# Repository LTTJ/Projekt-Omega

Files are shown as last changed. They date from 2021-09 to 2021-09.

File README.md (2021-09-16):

# Projekt-Omega

## Inhaltsverzeichnis
* [Kurzbeschreibung](#kurzbeschreibung)
* [Hardware](#hardware)
* [Software](#software)
  * [Indoor](#indoor)
  * [Outdoor](#outdoor)
  * [APP](#app)
  * [Node-RED](#node-red)
 
## Kurzbeschreibung
Dies ist "Projekt-Omega" - ein Smart-Home Projekt, welches für das Modul Soft Skills und Technische Kompetenzen als Prüfungsleistung entstanden ist. Die Aufgabe war es, ein Gerät zu entwickeln, das den Alltag angenehmer gestaltet oder ein konkretes Problem löst. Als weitere Bedingung musste mindestens ein Teil des Gadgets aus dem 3D-Drucker oder dem Lasercutter kommen. 

Das Ergebnis besteht aus zwei Prototypen: das Indoor-Haus und das Outdoor-Haus.
Prototyp-Drinnen
Prototyp-Draußen

## Hardware
Indoor-Haus:
* WEMOS D1 mini
* OLED Display
* DC Power Shield
* Rotary Encoder
* DHT Shield
* MQ-3 Sensor
* Kipp-Schalter
* Buzzer Shield
* Tripler Base

Outdoor-Haus:
* WEMOS D1 mini
* Battery Shield

Im Folgenden sind die Schaltpläne der beiden Häuser dargestellt.
Schaltplan-Indoor
Schaltplan-Outdoor

## Software
# Indoor
Software-Indoor

Die Software für das Indoor Haus ist einfach zusammenfassen, bietet jedoch eine gewisse Komplexität. Wurde die "requestData"-Flag gesetzt, so wird über MQTT die Node-RED Instanz angestoßen. Diese fordert dann bei der entsprechenden API die benötigten Daten an. Diese Daten werden an das Haus zurückgeschickt und können in der "handle MQTT" Phase verarbeitet werden. 

Nach der Verarbeitung sämtlicher MQTT Nachrichten wird geprüft, ob noch weitere Anfragen verarbeitet werden müssen oder ob der Bildschirm deaktiviert ist. Ist dies der Fall, werden die Displays geleert und die Schleife springt zum Anfang zurück. Die Variable "lightOn" kann mittels MQTT, also der App, und per Interrupt an dem Schalter vorne am Haus verändert werden.

Sind die Displays hingegen aktiviert und sollen Daten anzeigen, wird auf einem Display ein Auswahlmenü eingeblendet und auf dem anderen Display werden die Daten angezeigt. Mithilfe des Drehimpulsgebers (Schornstein) ist das Menü navigierbar. Auch diese Interaktion wird über Interrupt und die App realisiert, sodass nicht immer in der Loop erfragt werden muss, ob eine Auswahl stattgefunden hat.

# Outdoor

Software-Outdoor

Das Outdoor-Haus erlaubt keine Interaktion und ist so implementiert, dass es von überall Daten aufnehmen und an das Indoor-Haus senden kann. Dazu verbindet sich der Mikrocontroller zuerst mit dem WiFi und baut eine Verbindung zum MQTT-Broker auf. Daraufhin folgt eine Aufnahmereihe von 10 Aufnahmen, aus welchen ein Mittelwert errechnet wird. Ist dies geschehen, werden die Daten mittels MQTT an alle abonnierenden MQTT-Teilnehmer gesendet (Indoor-Haus). Abschließend geht der Controller für eine Minute in den Deep Sleep Modus. Um aus diesem Modus wieder "erwachen" zu können, müssen der D0 und der RST Pin miteinander verbunden sein. Die Nutzung des Deep Sleep Modus hat zwei verschiedene Gründe:

* Der Wemos d1 Mini produziert im Dauerbetrieb eine enorme Menge an Wärme, welche unweigerlich die Aufnahme der Temperaturwerte verfälscht. In einigen Tests wurden Temperaturabweichungen bis zu 10 °C festgestellt.
* Da der Wemos eine Minute lang nahezu ausgeschaltet ist, wird dabei keine Energie verbraucht und der Akku muss seltener geladen werden.

## Bibliotheken
Um das Projekt realisieren zu können, wurden diverse Bibliotheken verwendet. Diese Bibliotheken können alle im Library Manger der Arduino IDE heruntergeladen werden:

- "Adafruit GFX Library" by Adafruit, v1.10.10
- "Adafruit SSD1306 Wemos Mini OLED" by Adafruit + mcauser, v1.1.2
- "ArduinoMqttClient" by Arduino, v0.1.5
- "WiFiManager" by tzapu,tablatronix, v2.0.3-alpha
- "DHT sensor library" by Adafruit, v1.3.9
- "Time" by Michael Margolis, v1.6.1 (https://github.com/PaulStoffregen/Time)

<p>Da die Bibliothek "Adafruit SSD1306 Wemos Mini OLED" die selben Klassennamen hat wie die Bibliothek "Adafruit SSD1306" by Adafruit, besteht die Gefahr, dass der Compiler nicht die richtige Klasse zuordnen kann. Um dieses Problem zu umgehen, wurden die Klassen in der Bibliothek "Adafruit SSD1306 Wemos Mini OLED" mittels find and replace so bearbeitet, dass alle Klassennamen um den Suffix "_WEMOS" ergänzt wurden. Auf diese Weise können beide Bibliotheken simultan verwendet werden.

# APP

Die Implementierung der App erfolgte online mit Hilfe der Website MIT App Inventor. Durch die Erweiterung eines Beispielprogramms, welches bereits MQTT implementiert hatte, konnte relativ simpel eine einfache App gestaltet und mit MQTT-Funktionalität ausgestattet werden.

Blynk kam in diesem Projekt nicht mehr zum Einsatz. Grund dafür ist Blynks neuer Businessplan, der nicht mit Zielen des Projekts verainbar ist.

# Node-RED

Node-RED-flow

Der Node-RED-Flow ist aktuell darauf begrenzt, Anfragen an die SpaceX-API zu triggern und die Daten dann wieder mittels MQTT zu übermitteln.

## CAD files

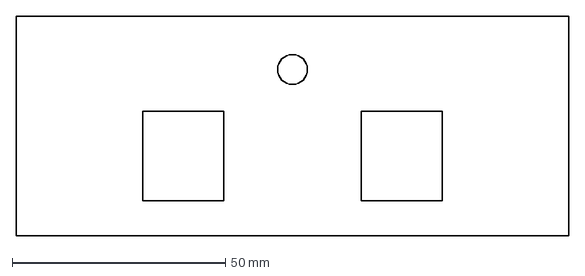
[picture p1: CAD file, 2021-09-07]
Hardware/Home/DXF/wood_front.dxf
129.5 x 51.5 mm

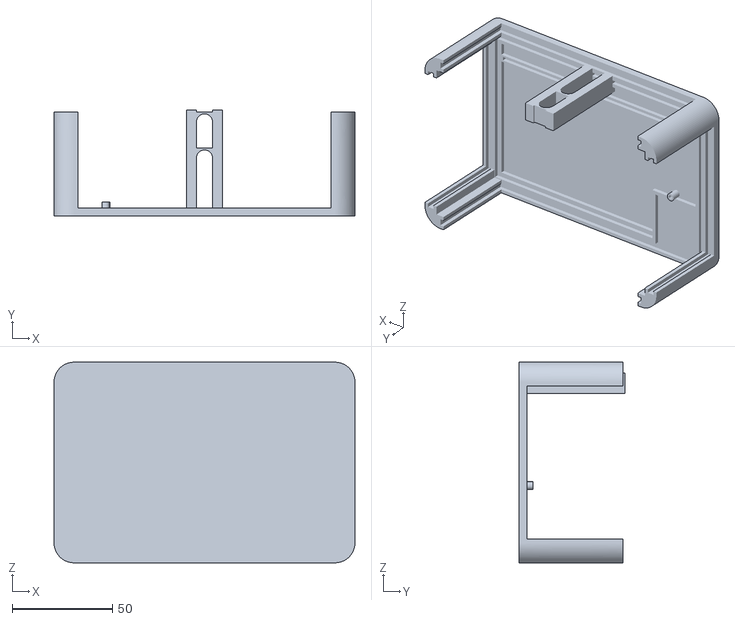
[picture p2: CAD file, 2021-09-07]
Hardware/Home/STL/bottom.stl
150.0 x 53.0 x 100.0

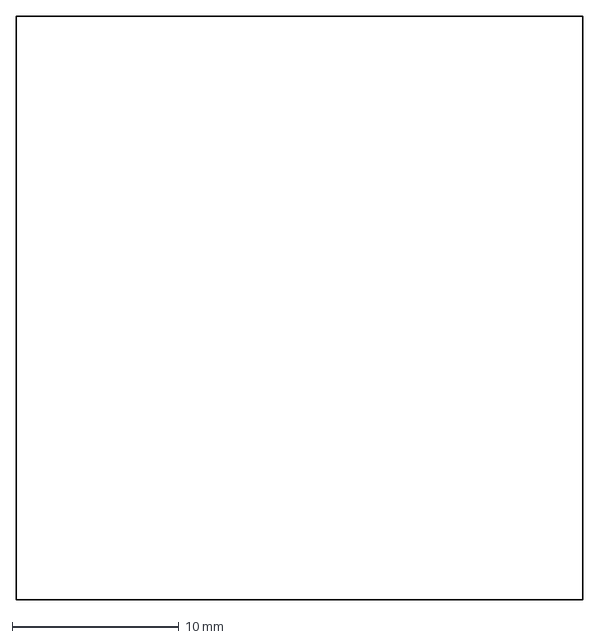
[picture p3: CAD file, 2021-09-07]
Hardware/SmallHome/DXF/wood_small_small.dxf
34.0 x 35.0 mm

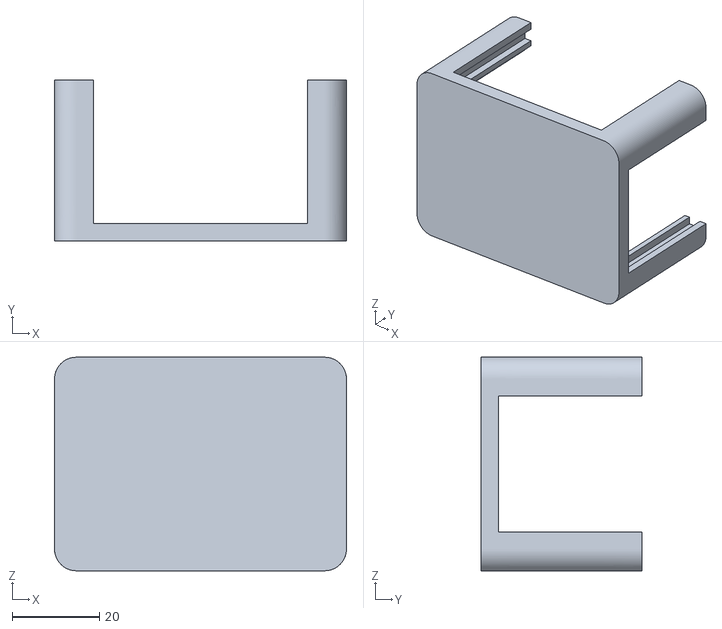
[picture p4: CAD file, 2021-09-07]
Hardware/SmallHome/STL/small_bottom.stl
67.0 x 37.0 x 49.0

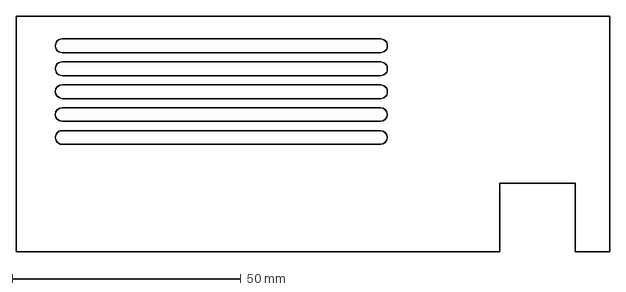
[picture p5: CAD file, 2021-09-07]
Hardware/Home/DXF/wood_back.dxf
129.5 x 51.5 mm

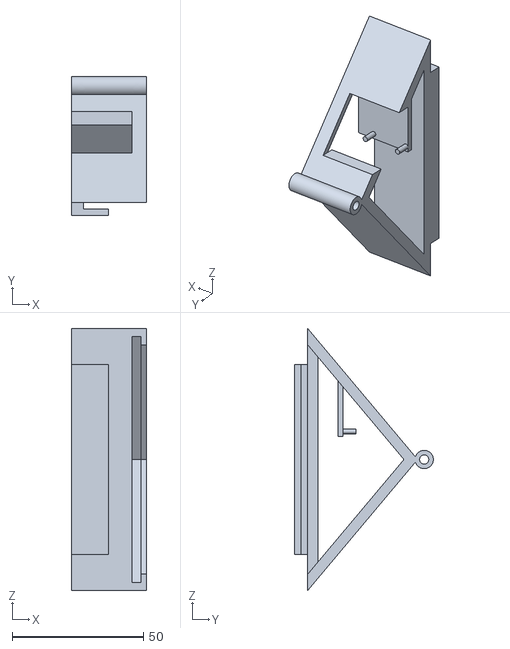
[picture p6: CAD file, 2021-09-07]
Hardware/Home/STL/roof_foot_left.stl
28.5 x 53.0 x 100.0

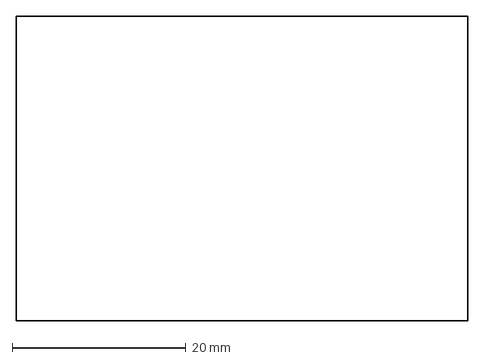
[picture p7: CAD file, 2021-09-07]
Hardware/SmallHome/DXF/wood_small_big.dxf
52.0 x 35.0 mm

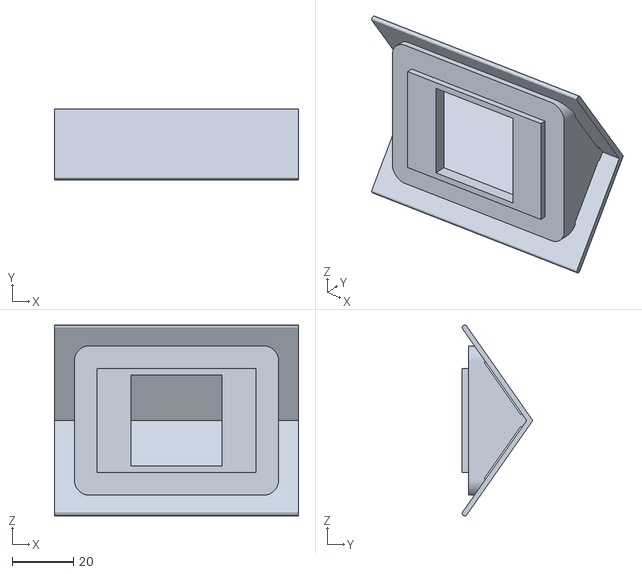
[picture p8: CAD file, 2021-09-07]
Hardware/SmallHome/STL/small_top.stl
80.0 x 23.2 x 62.6

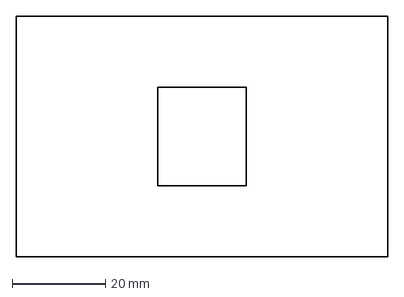
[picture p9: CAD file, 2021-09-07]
Hardware/Home/DXF/wood_right.dxf
79.5 x 51.5 mm

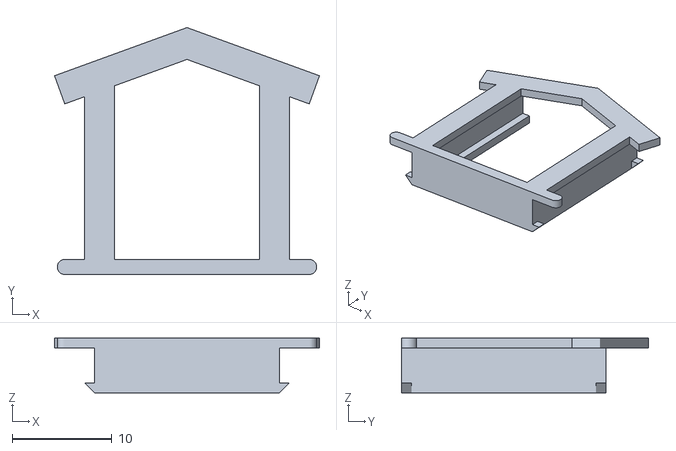
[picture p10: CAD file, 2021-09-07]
Hardware/Home/STL/window_side.stl
26.6 x 24.7 x 5.50

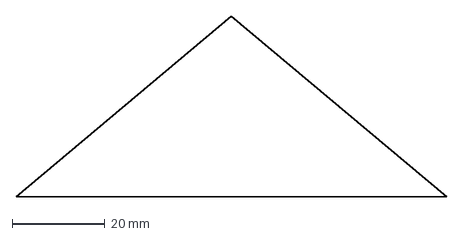
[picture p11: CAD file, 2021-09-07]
Hardware/Home/DXF/wood_roof_right.dxf
93.0 x 39.0 mm

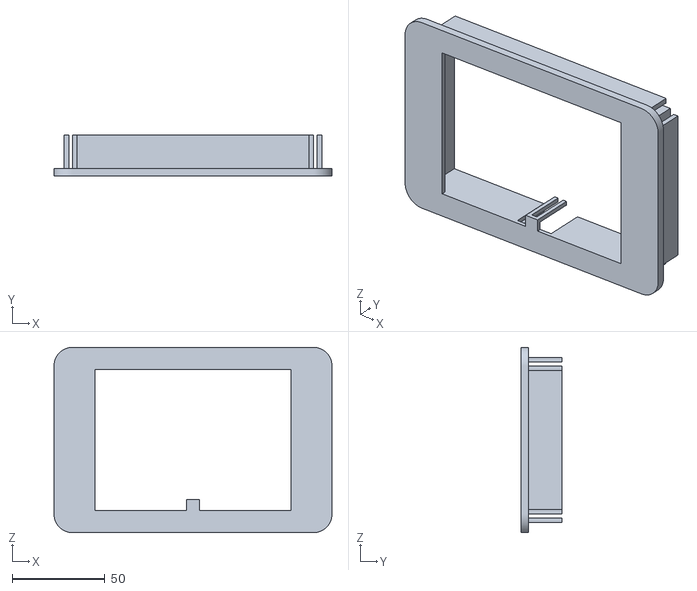
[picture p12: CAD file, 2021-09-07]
Hardware/Home/STL/top.stl
150.0 x 22.0 x 100.0

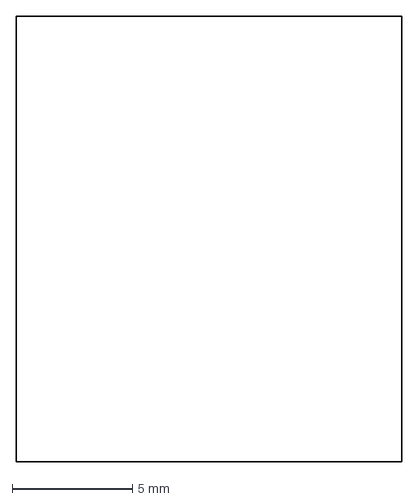
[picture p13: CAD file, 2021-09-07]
Hardware/Home/DXF/window_pane.dxf
16.0 x 18.5 mm

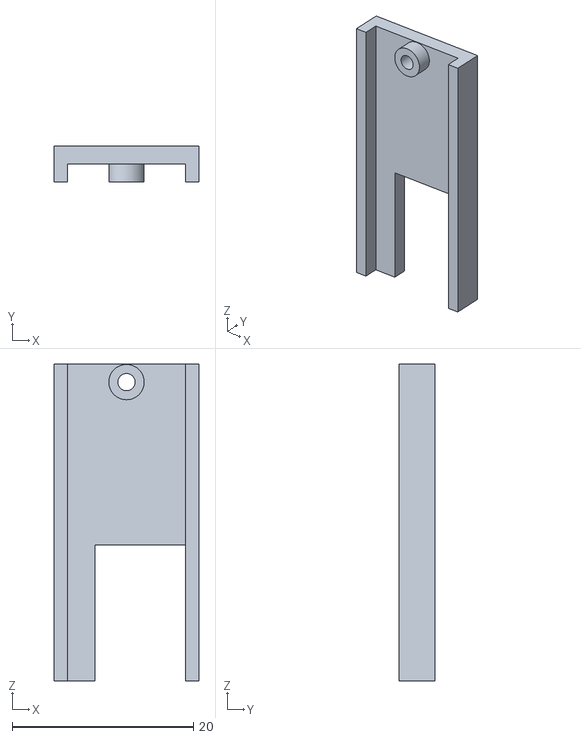
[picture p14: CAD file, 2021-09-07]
Hardware/Home/STL/power_halterung.stl
16.0 x 4.00 x 35.0

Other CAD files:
Hardware/Home/DXF/wood_roof_front.dxf
Hardware/Home/STL/roof_foot_right.stl
Hardware/Home/DXF/wood_left.dxf
Hardware/Home/STL/roof.stl
Hardware/Home/DXF/wood_roof_back.dxf
Hardware/Home/DXF/wood_roof_left.dxf
Hardware/Home/Inventor/bottom.ipt
Hardware/Home/Inventor/chimney.ipt
Hardware/Home/Inventor/power_halterung.ipt
Hardware/Home/Inventor/roof.ipt
Hardware/Home/Inventor/roof_foot_left.ipt
Hardware/Home/Inventor/roof_foot_right.ipt
Hardware/Home/Inventor/top.ipt
Hardware/Home/Inventor/window_pane.ipt
Hardware/Home/Inventor/window_side.ipt
Hardware/Home/Inventor/wood_back.ipt
Hardware/Home/Inventor/wood_front.ipt
Hardware/Home/Inventor/wood_left.ipt
Hardware/Home/Inventor/wood_right.ipt
Hardware/Home/Inventor/wood_roof_back.ipt
Hardware/Home/Inventor/wood_roof_front.ipt
Hardware/Home/Inventor/wood_roof_left.ipt
Hardware/Home/Inventor/wood_roof_right.ipt
Hardware/Home/STL/chimney.stl
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

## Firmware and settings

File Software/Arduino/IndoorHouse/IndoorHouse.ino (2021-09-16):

/*
By LTTJ
~ September 2021
*/

// Einbinden der benötigten Bibliotheken
#include "secrets.h"
#include "Definitions.h"
// OLED
#include <SPI.h>
#include <Wire.h>
#include <Adafruit_GFX.h>
#include <Adafruit_SSD1306_WEMOS.h>

// MQTT
#include <ArduinoMqttClient.h>

// WIFI
#include <ESP8266WiFi.h>  //https://github.com/esp8266/Arduino
#include <WiFiManager.h>

// CLOCK
#include "Clock.h"
#include <WiFiUdp.h>
#include <TimeLib.h>

// DHT
#include <Adafruit_Sensor.h>
#include <DHT.h>
#include <DHT_U.h>

#include "Menu.h"
#include "Scroll.h"

// https://forum.arduino.cc/t/single-line-define-to-disable-code/636044/2
// Aktiviere und deaktiviere Spezielle Serialausgaben über eine einfache Flag.
// Dies macht es wesentlich einfacher mit dem Serial Monitor große Programme zu debuggen.
#define DEBUG true
#define DEBUG_SERIAL \
  if (DEBUG) Serial

#define DEBUG_DHT false
#define DEBUG_DHT_SERIAL \
  if (DEBUG_DHT) Serial

#define DEBUG_MQTT true
#define DEBUG_MQTT_SERIAL \
  if (DEBUG_MQTT) Serial


Adafruit_SSD1306_WEMOS display1(OLED_RESET);
Adafruit_SSD1306_WEMOS display2(OLED_RESET);

Menu menu;
Scroll scroll;


DHT_Unified dht(DHTPIN, DHTTYPE);

uint32_t delayMS;
uint32_t lastDHTCheck;


WiFiClient client;
WiFiUDP Udp;
MqttClient mqttClient(client);

Clock c;

volatile bool lightsOn = true;
volatile bool switchFlag = false;

volatile bool modeChanged = false;
volatile bool requestData = false;

// ISR für den Interrupt des Schalters an D5
ICACHE_RAM_ATTR void SWITCHHandler(void) {
  switchFlag = true;
  modeChanged = true;
  menu.setChanged(true);
  lightsOn = !lightsOn;
}


// Diese Variablen werden gebraucht, um festzustellen, ob und wie sich der Encoder gedreht hat
// volatile int count = 0;
volatile int lastCLK = 0;
volatile bool countChanged = false;


// Buffer für Daten, die sonst über MQTT wieder erfragt werden müssten
time_t prevDisplay = 0;  // when the digital clock was displayed

float outdoorTempPrev = 0;
float outdoorTemp = 0;
float outdoorHumidPrev = 0;
float outdoorHumid = 0;

float indoorTemp = 0;
float indoorTempPrev = 0;
float indoorHumid = 0;
float indoorHumidPrev = 0;

String SpaceXName;
String SpaceXLaunchDate;

// interrupt handlers
// drehen des Encoders
ICACHE_RAM_ATTR void ClockChanged(void) {
  int clkValue = digitalRead(CLK);  //Read the CLK pin level
  int dtValue = digitalRead(DT);    //Read the DT pin level
  if (lastCLK != clkValue) {
    lastCLK = clkValue;
    //  count += (clkValue != dtValue ? 1 : -1);  //CLK and inconsistent DT + 1, otherwise - 1
    if (clkValue != dtValue) {
      menu.increment();
    } else {
      menu.decrement();
    }
  }
  countChanged = true;
}

// klicken des Encoders
ICACHE_RAM_ATTR void SWChanged(void) {
  uint8_t oldMode = menu.getSelectedMode();
  menu.select();
  modeChanged = (oldMode != menu.getSelectedMode());
  requestData = true;
}


void setup() {
#if DEBUG_DHT == true || DEBUG == true || DEBUG_MQTT == true
  Serial.begin(115200);
#endif

  pinMode(SWITCHPIN, INPUT_PULLUP);
  attachInterrupt(digitalPinToInterrupt(SWITCHPIN), SWITCHHandler, CHANGE);

  pinMode(SW, INPUT_PULLUP);
  //digitalWrite(SW, HIGH);
  pinMode(CLK, INPUT_PULLUP);
  pinMode(DT, INPUT);
  attachInterrupt(digitalPinToInterrupt(CLK), ClockChanged, CHANGE);
  attachInterrupt(digitalPinToInterrupt(SW), SWChanged, FALLING);


  display1.begin(SSD1306_SWITCHCAPVCC, address1);
  display2.begin(SSD1306_SWITCHCAPVCC, address2);


  display1.setTextColor(WHITE);
  display1.clearDisplay();
  display1.setTextWrap(false);

  display2.setTextColor(WHITE);
  display2.clearDisplay();
  display2.setTextWrap(false);
  display2.setCursor(0, 0);
  display2.print("DHT init");
  display2.display();

  // Temp and Humidity Sensor init
  dht.begin();
  DEBUG_DHT_SERIAL.println(F("DHTxx Unified Sensor Example"));
  // Print temperature sensor details.
  sensor_t sensor;
  dht.temperature().getSensor(&sensor);
  DEBUG_DHT_SERIAL.println(F("------------------------------------"));
  DEBUG_DHT_SERIAL.println(F("Temperature Sensor"));
  DEBUG_DHT_SERIAL.print(F("Sensor Type: "));
  DEBUG_DHT_SERIAL.println(sensor.name);
  DEBUG_DHT_SERIAL.print(F("Driver Ver:  "));
  DEBUG_DHT_SERIAL.println(sensor.version);
  DEBUG_DHT_SERIAL.print(F("Unique ID:   "));
  DEBUG_DHT_SERIAL.println(sensor.sensor_id);
  DEBUG_DHT_SERIAL.print(F("Max Value:   "));
  DEBUG_DHT_SERIAL.print(sensor.max_value);
  DEBUG_DHT_SERIAL.println(F("°C"));
  DEBUG_DHT_SERIAL.print(F("Min Value:   "));
  DEBUG_DHT_SERIAL.print(sensor.min_value);
  DEBUG_DHT_SERIAL.println(F("°C"));
  DEBUG_DHT_SERIAL.print(F("Resolution:  "));
  DEBUG_DHT_SERIAL.print(sensor.resolution);
  DEBUG_DHT_SERIAL.println(F("°C"));
  DEBUG_DHT_SERIAL.println(F("------------------------------------"));
  // Print humidity sensor details.
  dht.humidity().getSensor(&sensor);
  DEBUG_DHT_SERIAL.println(F("Humidity Sensor"));
  DEBUG_DHT_SERIAL.print(F("Sensor Type: "));
  DEBUG_DHT_SERIAL.println(sensor.name);
  DEBUG_DHT_SERIAL.print(F("Driver Ver:  "));
  DEBUG_DHT_SERIAL.println(sensor.version);
  DEBUG_DHT_SERIAL.print(F("Unique ID:   "));
  DEBUG_DHT_SERIAL.println(sensor.sensor_id);
  DEBUG_DHT_SERIAL.print(F("Max Value:   "));
  DEBUG_DHT_SERIAL.print(sensor.max_value);
  DEBUG_DHT_SERIAL.println(F("%"));
  DEBUG_DHT_SERIAL.print(F("Min Value:   "));
  DEBUG_DHT_SERIAL.print(sensor.min_value);
  DEBUG_DHT_SERIAL.println(F("%"));
  DEBUG_DHT_SERIAL.print(F("Resolution:  "));
  DEBUG_DHT_SERIAL.print(sensor.resolution);
  DEBUG_DHT_SERIAL.println(F("%"));
  DEBUG_DHT_SERIAL.println(F("------------------------------------"));
  // Set delay between sensor readings based on sensor details.
  delayMS = sensor.min_delay / 1000;

  //display2.clearDisplay();
  display2.setCursor(0, 12);
  display2.print("DHT done");
  display2.display();

  // starting WiFi setup
  WiFiManager wifiManager;
  wifiManager.setWiFiAutoReconnect(true);
  DEBUG_SERIAL.println("starting connection");
  display1.clearDisplay();
  display1.println("connecting...");
  display1.display();
  wifiManager.autoConnect("IndoorHouse");
  DEBUG_SERIAL.println("connected...yeey :)");
  display1.clearDisplay();
  display1.println("connected!");
  display1.display();

  // MQTT setup
  mqttClient.setId("IndoorHouse");
  mqttClient.setUsernamePassword(username, password);

  // String willPayload = "oh no!";
  // bool willRetain = true;
  // int willQos = 1;

  // mqttClient.beginWill(willTopic, willPayload.length(), willRetain, willQos);
  // mqttClient.print(willPayload);
  // mqttClient.endWill();


  if (!mqttClient.connect(broker, port)) {
    DEBUG_MQTT_SERIAL.print("MQTT connection failed! Error code = ");
    DEBUG_MQTT_SERIAL.println(mqttClient.connectError());
    while (1)
      ;
  }
  mqttClient.subscribe(OUTDOOR_TEMP_TOPIC);
  mqttClient.subscribe(OUTDOOR_HUMID_TOPIC);
  mqttClient.subscribe(DISPLAY_SELECTION_TOPIC);
  mqttClient.subscribe(DISPLAY_ACTIVE_TOPIC);

  mqttClient.subscribe(API_SPACEX_NAME);
  mqttClient.subscribe(API_SPACEX_LAUNCHDATE);

  // ermittele Zeit mittels UDP
  Udp.begin(localPort);
  setSyncProvider(getNtpTime);
  setSyncInterval(300);
}

void loop() {
  // Falls Daten von Node-RED erfragt werden müssen, wird die requestData Flag gesetzt, sodass an dieser Stelle dann die Daten erbittet werden können.
  // Dies geschieht, indem eine entsprechende Nachricht an Node-RED geschickt wird, welche das Versenden der Daten triggert.
  if (requestData) {
    switch (menu.getSelectedMode()) {
      case SPACEX:
        mqttClient.beginMessage(API_SPACEX);
        mqttClient.print(1);
        mqttClient.endMessage();
        DEBUG_SERIAL.println("sending SpaceX request");
        break;
      default:
        break;
    }
    requestData = false;
  }

  // Falls MQTT Nachrichten kommen, verarbeite sie entsprechend
  handleMQTT();


  // Wenn wir kein Licht an haben, dann werden hier die Displays deaktiviert und das Programm braucht nicht weiter machen, da nichts mehr angezeigt werden soll -> return
  if (!lightsOn) {
    DEBUG_SERIAL.println("lights off");
    if (switchFlag) {
      display1.clearDisplay();
      display1.display();
      display2.clearDisplay();
      display2.display();
      DEBUG_SERIAL.println("displays off");
      switchFlag = false;
    }
    return;
  }


  // entsprechend des ausgewählten Mode im Menu werden bestimmte Anzeigen gerendert.
  switch (menu.getSelectedMode()) {
    case INDOOR_DATA_MODE:
      // get new data from the sensor periodically
      getDHTData();

      // display the indoor values
      if (indoorTempPrev != indoorTemp || indoorHumidPrev != indoorHumid || modeChanged) {
        display2.clearDisplay();
        display2.setCursor(0, 5);
        display2.print("Indoor");
        display2.setCursor(0, 15);
        display2.print(F("Tmp: "));
        display2.print(indoorTemp);
        // display2.println(F("°C"));

        display2.setCursor(0, 25);
        display2.print(F("Hum: "));
        display2.print(indoorHumid);
        display2.display();
        // display2.println(F("%"));
        indoorHumidPrev = indoorHumid;
        indoorTempPrev = indoorTemp;

        modeChanged = false;
      }
      break;
    case OUTDOOR_DATA_MODE:
      if (outdoorTempPrev != outdoorTemp || outdoorHumidPrev != outdoorHumid || modeChanged) {
        display2.clearDisplay();
        display2.setCursor(0, 5);
        display2.print("Outdoor");
        display2.setCursor(0, 15);
        display2.print(F("Tmp: "));
        display2.print(outdoorTemp);
        // display2.println(F("°C"));

        display2.setCursor(0, 25);

        display2.print(F("Hum: "));
        display2.print(outdoorHumid);
        //  display2.println(F("%"));

        display2.display();
        outdoorTempPrev = outdoorTemp;
        outdoorHumidPrev = outdoorHumid;
        modeChanged = false;
      }
      break;
    case DIGITAL_CLOCK:
      if (timeStatus() != timeNotSet) {
        if (now() != prevDisplay || modeChanged) {  //update the display only if time has changed
          prevDisplay = now();
          display2.clearDisplay();
          c.displayDigital(&display2, hour(), minute(), second());
          display2.display();
          modeChanged = false;
        }
      }
      break;
    case MIXED_CLOCK:
      if (timeStatus() != timeNotSet) {
        if (now() != prevDisplay || modeChanged) {  //update the display only if time has changed
          prevDisplay = now();
          display2.clearDisplay();
          c.displayMixed(&display2, hour(), minute(), second());
          display2.display();
          modeChanged = false;
        }
      }
      break;
    case SPACEX:
      if (modeChanged) {
        scroll.clear(&display2);
        scroll.setRow(0, SpaceXName);
        scroll.setRow(1, SpaceXLaunchDate);
        modeChanged = false;
      }
      scroll.update();
      scroll.show(&display2);
      break;
    case ANALOG_CLOCK:
    default:
      if (timeStatus() != timeNotSet) {
        if (now() != prevDisplay || modeChanged) {  //update the display only if time has changed
          prevDisplay = now();
          display2.clearDisplay();
          c.displayAnalog(&display2, hour(), minute(), second());
          display2.display();
          modeChanged = false;
        }
      }
  }


  // Zeichne das Menu
  if (menu.hasChanged()) {
    menu.show(&display1);
  }
}

void handleMQTT() {
  int messageSize = mqttClient.parseMessage();
  if (messageSize) {
    // we received a message, print out the topic and contents
    String topic = mqttClient.messageTopic();
    DEBUG_MQTT_SERIAL.print("Received a message with topic '");
    DEBUG_MQTT_SERIAL.print(topic);
    DEBUG_MQTT_SERIAL.print("', length ");
    DEBUG_MQTT_SERIAL.print(messageSize);
    DEBUG_MQTT_SERIAL.println(" bytes:");

    // use the Stream interface to print the contents
    String value = "";
    while (mqttClient.available()) {
      value += (char)mqttClient.read();
    }
    DEBUG_MQTT_SERIAL.println(value);
    DEBUG_MQTT_SERIAL.println();

    if (topic.equals(OUTDOOR_TEMP_TOPIC)) {
      outdoorTempPrev = outdoorTemp;
      outdoorTemp = value.toFloat();
    } else if (topic.equals(OUTDOOR_HUMID_TOPIC)) {
      outdoorHumidPrev = outdoorHumid;
      outdoorHumid = value.toFloat();
    } else if (topic.equals(DISPLAY_SELECTION_TOPIC)) {
      menu.setSelectedMode(value.toInt());
      modeChanged = true;
      requestData = true;
    } else if (topic.equals(DISPLAY_ACTIVE_TOPIC)) {
      switchFlag = true;
      modeChanged = true;
      lightsOn = value.toInt();
    } else if (topic.equals(API_SPACEX_NAME)) {
      DEBUG_SERIAL.print("Name: ");
      DEBUG_SERIAL.println(value);
      SpaceXName = value;
      modeChanged = true;
    } else if (topic.equals(API_SPACEX_LAUNCHDATE)) {
      DEBUG_SERIAL.print("Date: ");
      DEBUG_SERIAL.println(value);
      SpaceXLaunchDate = value;
      modeChanged = true;
    }
  }
}

void getDHTData() {
  if (millis() - delayMS > lastDHTCheck) {
    indoorTempPrev = indoorTemp;
    sensors_event_t event;
    dht.temperature().getEvent(&event);

    if (isnan(event.temperature)) {
      DEBUG_DHT_SERIAL.println(F("Error reading temperature!"));
    } else {
      DEBUG_DHT_SERIAL.print(F("Temperature: "));
      DEBUG_DHT_SERIAL.print(event.temperature);
      DEBUG_DHT_SERIAL.println(F("°C"));
      indoorTemp = event.temperature;
    }

    // Get humidity event and print its value.
    dht.humidity().getEvent(&event);
    if (isnan(event.relative_humidity)) {
      DEBUG_DHT_SERIAL.println(F("Error reading humidity!"));
    } else {
      DEBUG_DHT_SERIAL.print(F("Humidity: "));
      DEBUG_DHT_SERIAL.print(event.relative_humidity);
      DEBUG_DHT_SERIAL.println(F("%"));
      indoorHumid = event.relative_humidity;
    }
    lastDHTCheck = millis();
  }
}


// NTP STUFF
time_t getNtpTime() {
  IPAddress ntpServerIP;  // NTP server's ip address

  while (Udp.parsePacket() > 0)
    ;  // discard any previously received packets
  DEBUG_SERIAL.println("Transmit NTP Request");
  // get a random server from the pool
  WiFi.hostByName(ntpServerName, ntpServerIP);
  DEBUG_SERIAL.print(ntpServerName);
  DEBUG_SERIAL.print(": ");
  DEBUG_SERIAL.println(ntpServerIP);
  sendNTPpacket(ntpServerIP);
  uint32_t beginWait = millis();
  while (millis() - beginWait < 1500) {
    int size = Udp.parsePacket();
    if (size >= NTP_PACKET_SIZE) {
      DEBUG_SERIAL.println("Receive NTP Response");
      Udp.read(packetBuffer, NTP_PACKET_SIZE);  // read packet into the buffer
      unsigned long secsSince1900;
      // convert four bytes starting at location 40 to a long integer
      secsSince1900 = (unsigned long)packetBuffer[40] << 24;
      secsSince1900 |= (unsigned long)packetBuffer[41] << 16;
      secsSince1900 |= (unsigned long)packetBuffer[42] << 8;
      secsSince1900 |= (unsigned long)packetBuffer[43];
      return secsSince1900 - 2208988800UL + timeZone * SECS_PER_HOUR;
    }
  }
  DEBUG_SERIAL.println("No NTP Response :-(");
  return 0;  // return 0 if unable to get the time
}


// send an NTP request to the time server at the given address
void sendNTPpacket(IPAddress &address) {
  // set all bytes in the buffer to 0
  memset(packetBuffer, 0, NTP_PACKET_SIZE);
  // Initialize values needed to form NTP request
  // (see URL above for details on the packets)
  packetBuffer[0] = 0b11100011;  // LI, Version, Mode
  packetBuffer[1] = 0;           // Stratum, or type of clock
  packetBuffer[2] = 6;           // Polling Interval
  packetBuffer[3] = 0xEC;        // Peer Clock Precision
  // 8 bytes of zero for Root Delay & Root Dispersion
  packetBuffer[12] = 49;
  packetBuffer[13] = 0x4E;
  packetBuffer[14] = 49;
  packetBuffer[15] = 52;
  // all NTP fields have been given values, now
  // you can send a packet requesting a timestamp:
  Udp.beginPacket(address, 123);  //NTP requests are to port 123
  Udp.write(packetBuffer, NTP_PACKET_SIZE);
  Udp.endPacket();
}

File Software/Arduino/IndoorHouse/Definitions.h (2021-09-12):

#ifndef DEFINITIONS
#define DEFINITIONS

//-------- PINS ---------//

#define DHTPIN D4  // Digital pin connected to the DHT sensor

#define CLK D7
#define DT D3
#define SW D6

#define SWITCHPIN D5

#define BUZZER D8

//-------- DEFINITIONS ---------//

// DHT
#define DHTTYPE DHT11  // DHT 11

// OLED
#define OLED_RESET 0
const int address1 = 0x3C;
const int address2 = 0x3D;
const int DISPLAY_WIDTH = 64;
const int DISPLAY_HEIGHT = 48;

// DISPLAY MODES
const uint8_t INDOOR_DATA_MODE = 0;
const uint8_t OUTDOOR_DATA_MODE = 1;
const uint8_t ANALOG_CLOCK = 2;
const uint8_t DIGITAL_CLOCK = 3;
const uint8_t MIXED_CLOCK = 4;
const uint8_t SPACEX = 5;
const uint8_t MODE_COUNT = 6;
// Auflistung der Strings, welche im Menü angezeigt werden.
// Reihenfolge muss mit den Mode-Values übereinstimmen!
const static char *MODES[MODE_COUNT] = { "Indoor", "Outdoor", "Analog", "Digital", "Mixed", "SpaceX" };

// UDP TIME
const static char ntpServerName[] = "de.pool.ntp.org";
const static int timeZone = 2;
const static unsigned int localPort = 8888;

// NTP
const static int NTP_PACKET_SIZE = 48;
static byte packetBuffer[NTP_PACKET_SIZE];

// MQTT
const char OUTDOOR_TEMP_TOPIC[] = "Projekt-Omega/outdoor/dht/temp";
const char OUTDOOR_HUMID_TOPIC[] = "Projekt-Omega/outdoor/dht/humid";
const char DISPLAY_SELECTION_TOPIC[] = "Projekt-Omega/indoor/display/mode";
const char DISPLAY_ACTIVE_TOPIC[] = "Projekt-Omega/indoor/display/active";

const char API_SPACEX[] = "Projekt-Omega/api/spaceX";
const char API_SPACEX_NAME[] = "Projekt-Omega/api/spaceX/name";
const char API_SPACEX_LAUNCHDATE[] = "Projekt-Omega/api/spaceX/launchDate";

#endif

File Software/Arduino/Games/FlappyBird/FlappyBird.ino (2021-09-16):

/*
By Jonas Pohl
~ September 2021
*/

#include <Wire.h>
#include "Definitions.h"
#include <Adafruit_GFX.h>
#include <Adafruit_SSD1306_WEMOS.h>
#include "Pipe.h"
#include "Bird.h"

#define OLED_RESET 0
Adafruit_SSD1306_WEMOS display(OLED_RESET);
Pipe pipes[4] = { (64), (96), (128), (160) };

Bird bird;
uint64_t lastPress;
const long DEBOUNCE = 25;


void setup() {


  pinMode(BTN, INPUT);
  lastPress = millis();
  display.begin(SSD1306_SWITCHCAPVCC, 0x3C);
  display.setTextColor(WHITE);
  display.clearDisplay();
}



void loop() {
  if (bird.isDead()) {
    display.clearDisplay();
    display.setCursor(0, DISPLAY_HEIGHT/2);
    display.setTextSize(1);
    display.print("Game Over");
    display.display();
    return;
  }


  if (digitalRead(BTN) == LOW) {
    if (millis() - lastPress >= DEBOUNCE) {
      bird.fly();
      lastPress = millis();
    }
  }

  display.clearDisplay();

  display.setCursor(0, 0);
  display.print(Pipe::score);

  for (int i = 0; i < 4; i++) {
    pipes[i].update();
    pipes[i].show(&display);
    bird.check(&pipes[i]);
  }
  bird.update();
  bird.show(&display);

  display.display();
}

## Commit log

2021-09-07 home models
    [bottom.ipt, bottom.stl, chimney.ipt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]
2021-09-07 small home models
    [small_bottom.ipt, small_bottom.stl, small_top.ipt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]
2021-09-07 Initial IndoorHouse Code
    - Ansteuerung beider Displays
    - Verbinden mit WiFi via WiFi Manager
    - Interrupt für Schalter an der Vorderwand
    - Zeitanzeige mit Internetzeit (NTP)
2021-09-08 Adding DHT measurement
    Der DHT Sensor wird jetzt auch ausgelesen und die Werte werden auf einem
    OLED angezeigt.
2021-09-08 Adding MQTT base logic
    Die Grundlogik zum verbinden mit einem MQTT Broker wurde implementiert.
    [IndoorHouse.ino]
2021-09-09 Adding Outoor House Logic
    Das Outdoor Haus bekommt hiermit seine Logik. Es kann sich mittels WiFi
    Manager mit dem WLAN verbinden und sendet via MQTT einen Mittelwert der
    letzten 10 Messungen der Temperatur und Luftfeuchtigkeit an einen
    Broker.
    [OutdoorHouse.ino]
2021-09-09 Adding MQTT Support
    Auf einem Display kann nun mittels des Buttons des Encoders durch
    verschiedene Menus geschaltet werden. Diese zeigen Daten von selbst
    gemessenen Werten, von Werten des Outdoor-Hauses oder den Counter des
    Encoders an.
    Weiterhin wurde eine Debug Logik implementiert, welche es leichter
    macht, verschiedene Bereiche mit dem Serial Monitor zu debuggen.
2021-09-10 Adding Menu to the System
    Es wurde ein Menu erstellt, welches es ermöglicht, zwischen
    verschiedenen Anzeigen auszuwählen. Dabei dient ein Display für die
    Anzeige des Menus, auf dem anderen Bildschirm wird dann die
    entsprechende Auswahl angezeigt.
2021-09-10 Changing MQTT Topics
    Die MQTT Topics wurden so angepasst, dass sie besser in die gesamte
    Struktur passen.
2021-09-10 Adding App support
    Es kann nun mit einer App ein Modus aus dem Menu ausgewählt werden,
    welcher dann auf dem Display angezeigt wird. Dabei wird auch das Menu
    selbst angepasst.
2021-09-11 Adding Mixed Clock and Node-RED connection
    Es wurde eine weitere Uhrendarstellung hinzugefügt, welche eine Mischung
    aus einer analogen und einer digitalen Uhr ist.
    Weiterhin wurde eine Anbindung an Node-RED mittels MQTT geschaffen,
    sodass nun Daten vom Haus über Node-RED von verschiedenen APIs abgefragt
    werden können. Als Beispiel dient erstmal die API, welche über Starts
    von SpaceX Raketen informiert.
2021-09-12 Scroll Display for API Display
    Es wurde eine Klasse implementiert, welche es erlaubt, einen String in
    einer Zeile anzuzeigen. Sollte der String zu lang für die Zeile sein,
    dann wird der String über die Zeile gescrollt. Dabei wird immer
    gewartet, bis der letzte String durchgelaufen ist, und erst dann werden
    die Strings "Neu gestartet".
2021-09-12 Adding Active Option via App
    Man kann nun auch mittels der App die Displays an- bzw. ausschalten.
2021-09-16 Adding Node-RED flow
2021-09-16 Adding Libraries
    Eine Auflistung der genutzten Bibliotheken und der Besonderheiten beim Einbinden wurde hinzugefügt.
2021-09-16 Fixing Menu display Issue
    Wenn man das Menu ausgeschaltet und dann wieder angeschaltet hat, wurde
    es nicht wieder neu gezeichnet. Dies hat daran gelegen, dass die
    Funktion zum zeichnen nicht aufgerufen wurde, nachdem der Switch
    Interrupt ausgelöst hat. Es wird nun die Eigenschaft des Menus gesetzt,
    dass sich das Menu geändert hat, sodass es neu gezeichnet werden muss.
    [IndoorHouse.ino]
